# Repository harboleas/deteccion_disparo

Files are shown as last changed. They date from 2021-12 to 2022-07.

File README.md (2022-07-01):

Dispositivo para la detección del disparo de un FAL con un piezoelectrico.
--------------------------------------------------------------------------

En este trabajo se realizaron las siguientes tareas:

* Relevamiento de la señal del piezo, en las condiciones de carga y disparo del FAL, mediante un osciloscopio y su grabacion en formato CSV.

* El desarrollo de un software con interfaz gráfica, en lenguaje C#, 
para simular las señales del piezo en la carga y disparo del FAL.
Este software permite leer los archivos CSV generados por el osciloscopio, y transmitir esa informacion, mediante una comunicación serie, a un Arduino para su procesamiento (en modo simulación).    

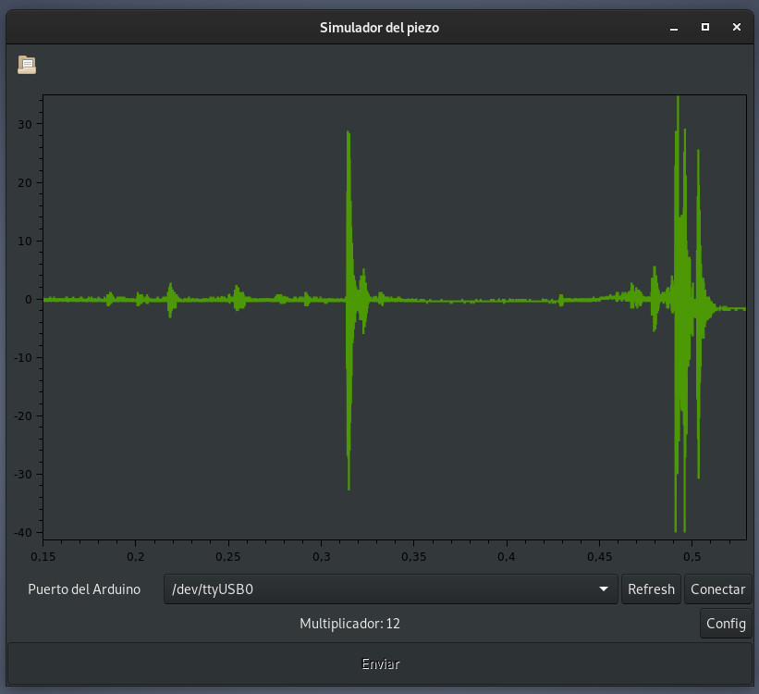
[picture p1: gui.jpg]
GUI


* El desarrollo del firmware para un Arduino que permite analizar la señal que llega del piezo, a través del puerto ADC, y detectar cuando se produce eldisparo del FAL.
El firmware también posee un modo simulación donde obtiene la informacion de la señal por el puerto serie.  

* Diseño en CAD del contenedor del dispositivo y su impresión en 3D
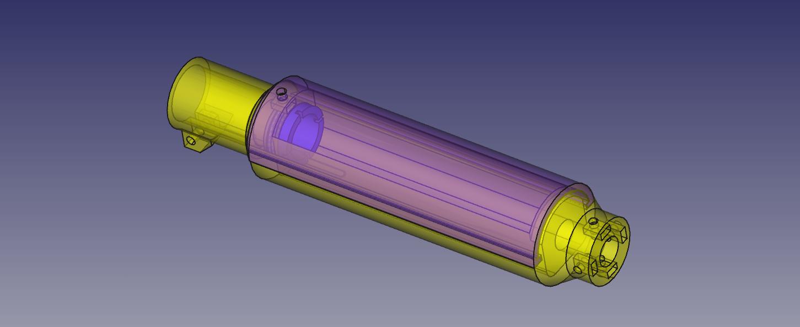
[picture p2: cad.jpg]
Mecanica

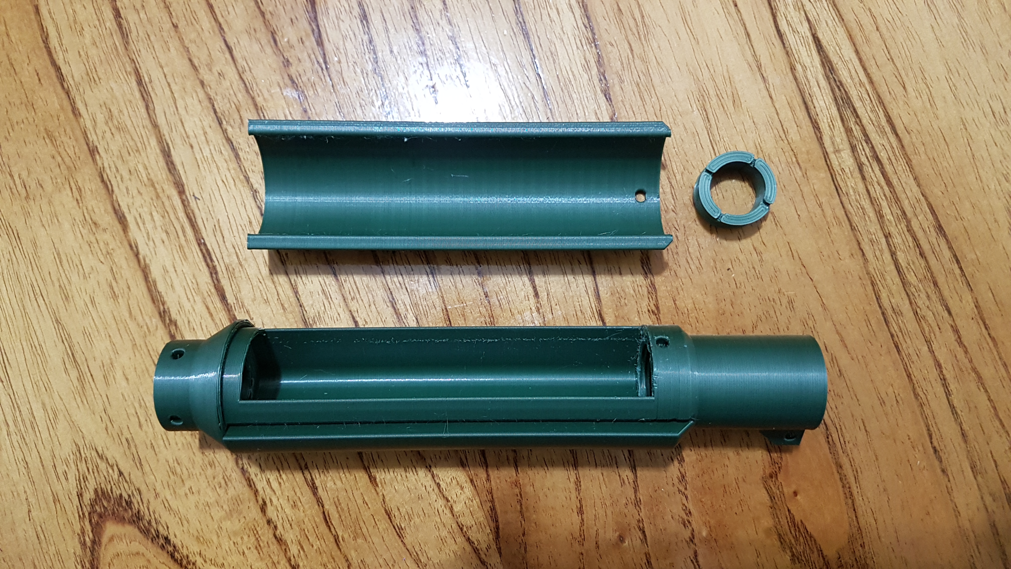
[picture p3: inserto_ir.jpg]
Mecanica2


Maquina de estados para la deteccion de la señal de disparo
-----------------------------------------------------------

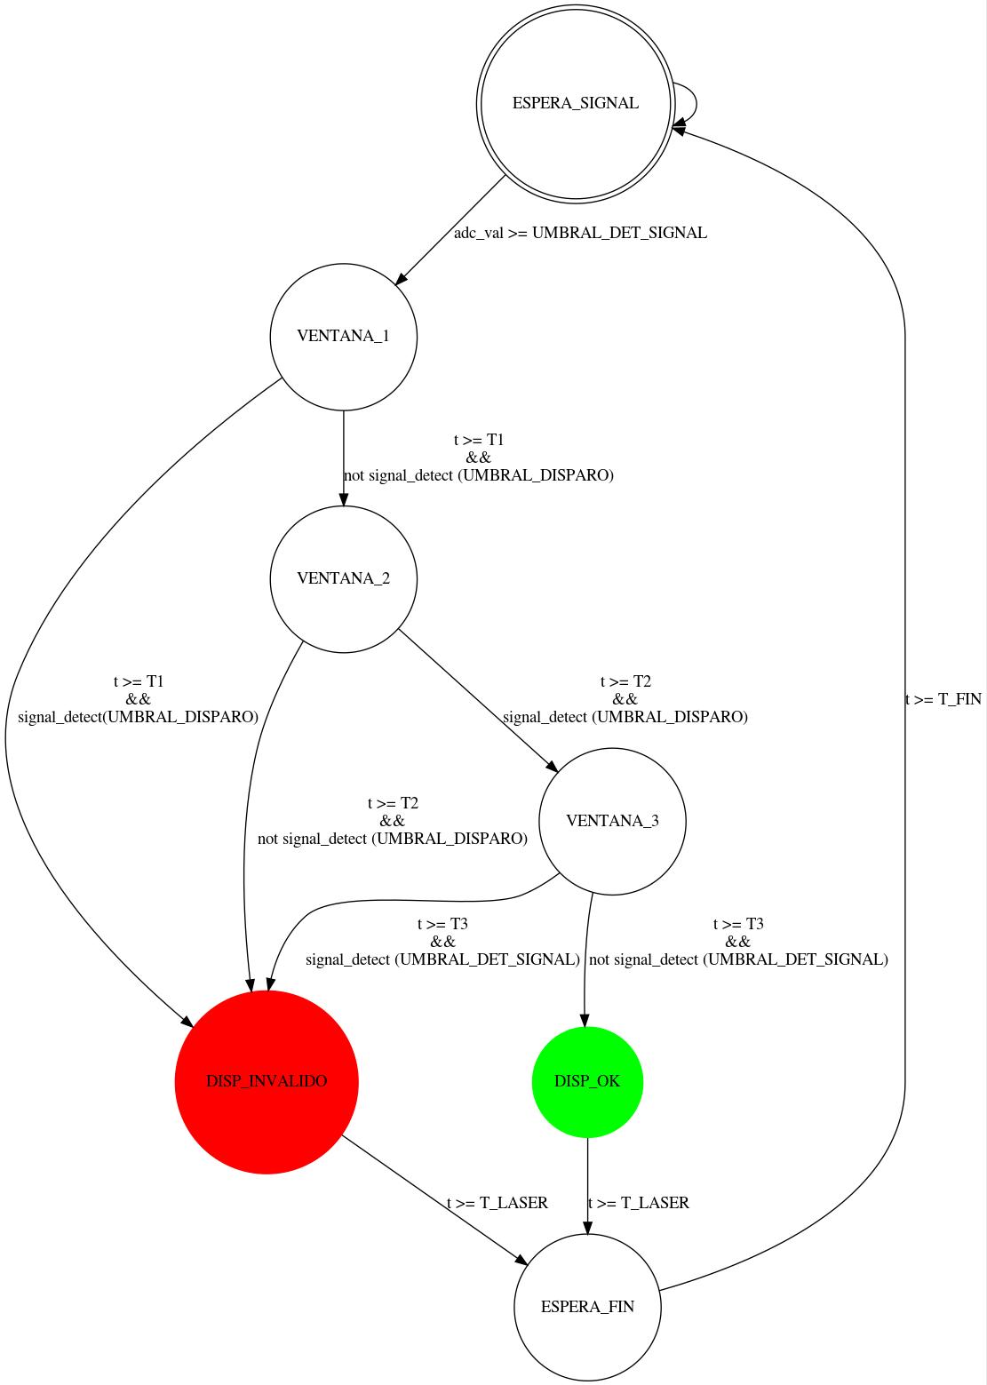
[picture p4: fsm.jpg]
FSM


* Diseño del PCB

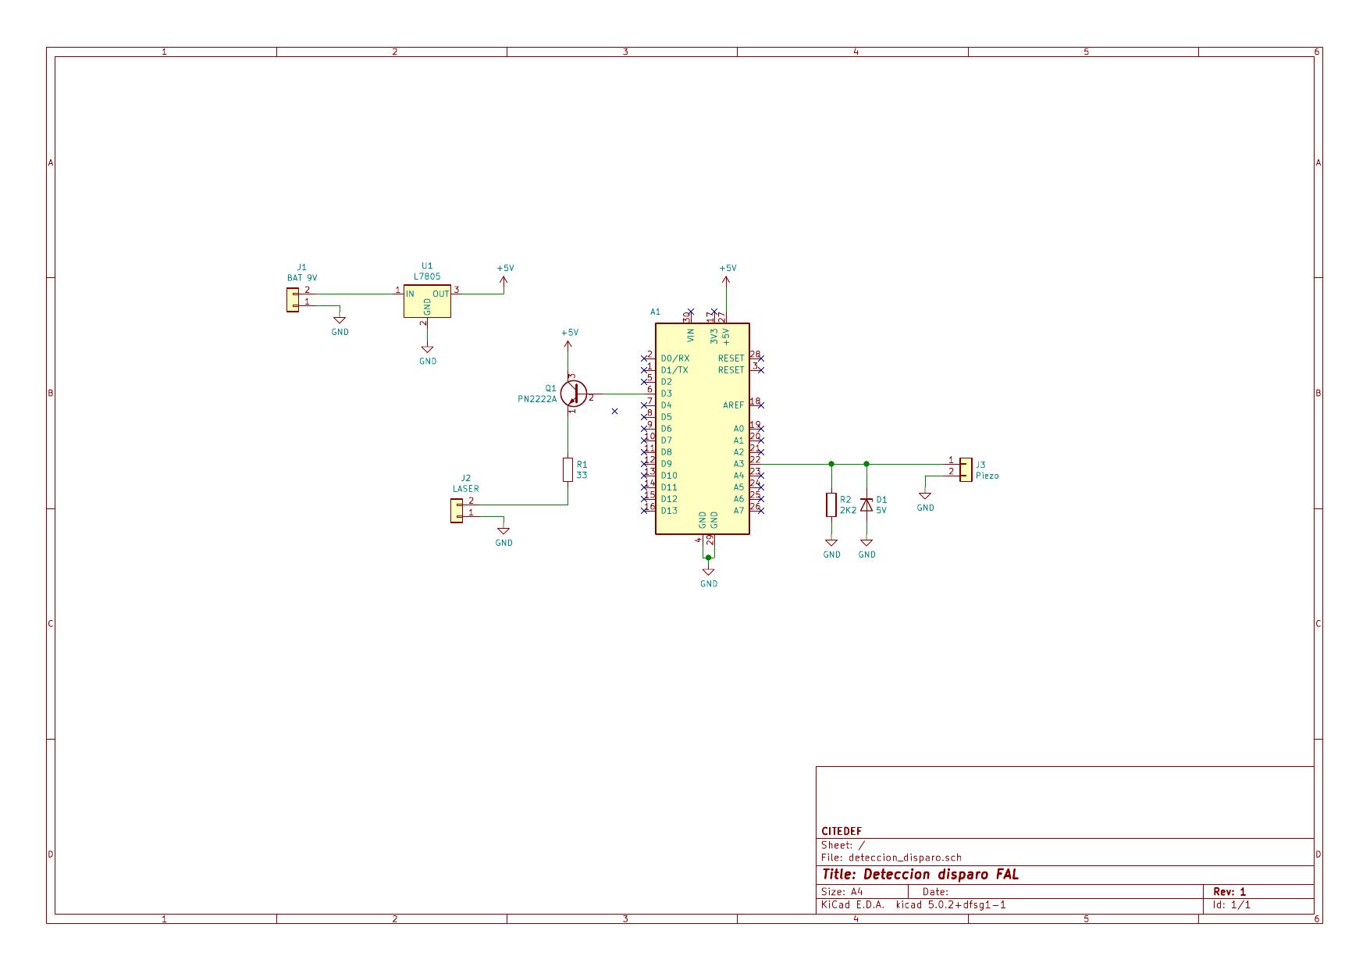
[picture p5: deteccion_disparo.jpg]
PCB


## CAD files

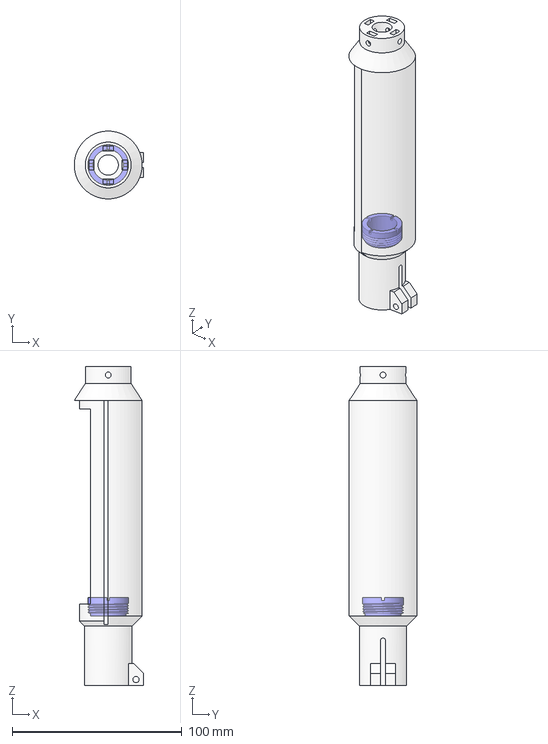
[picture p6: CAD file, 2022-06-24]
mecanica/inserto_ir.FCStd
40.9 x 40.0 x 188.0 mm

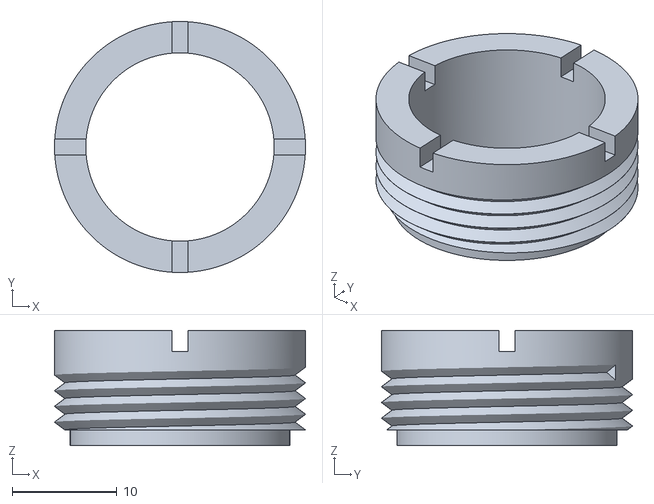
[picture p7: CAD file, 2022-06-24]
mecanica/inserto_ir_rosca.stl
24.0 x 24.0 x 11.0

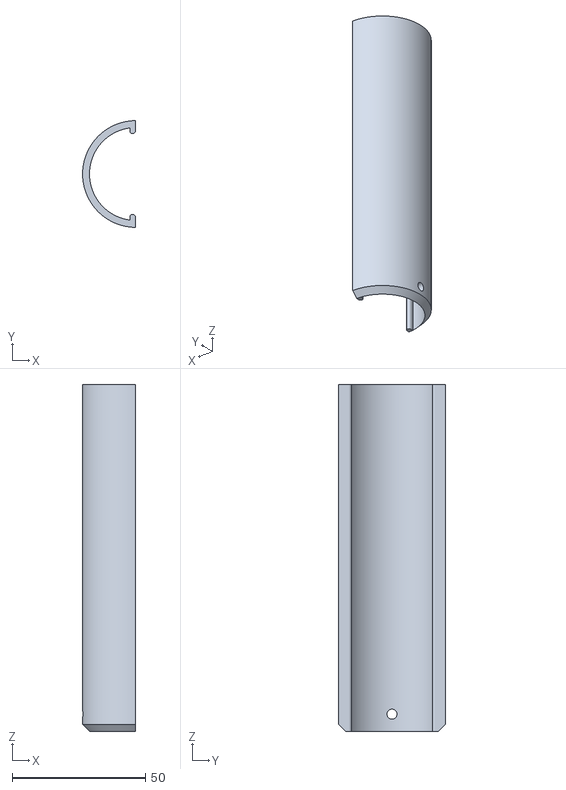
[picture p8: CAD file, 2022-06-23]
mecanica/inserto_ir_tapa.stl
19.8 x 40.0 x 130.0

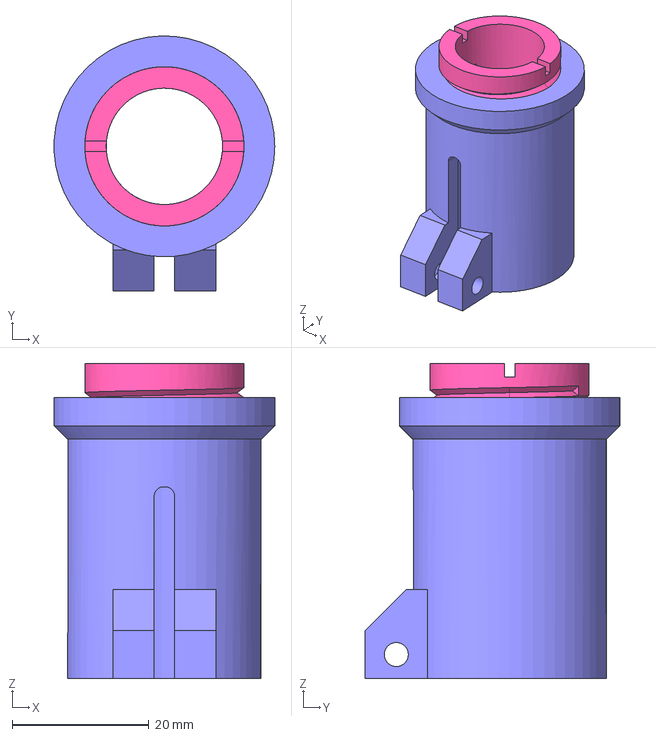
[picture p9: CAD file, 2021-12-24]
mecanica/soporte_piezo.FCStd
32.2 x 37.2 x 46.0 mm

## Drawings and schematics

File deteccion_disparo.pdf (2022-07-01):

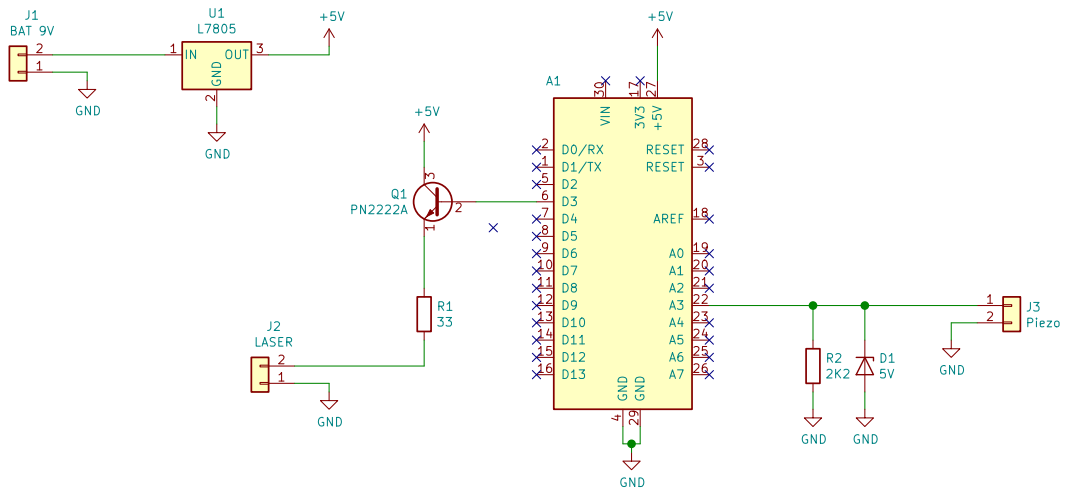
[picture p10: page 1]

File: deteccion_disparo.sch Sheet: / CITEDEF

Id: 1/1 Title: Deteccion disparo FAL

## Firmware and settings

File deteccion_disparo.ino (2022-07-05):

// Deteccion de disparo para SIMTAP

// Descomentar la siguiente linea para simulacion del piezo  
//#define SIMU

// Definicion de pines
#define ADC_PIN 3
#define LASER_PIN 3
#define TESTIGO_PIN 13
#define DISP_INVALIDO_PIN 2

// Umbral para la deteccion
#define UMBRAL_DET_SIGNAL 27 // 0.13V    92   // 0.45 Volts
#define UMBRAL_DISPARO 870// 4.25 Volts

// Duracion de las ventanas de deteccion en microsegundos
#define T1 4000L
#define T2 19000L
#define T3 5000L

// Duracion del pulso del laser en microsegundos
#define T_LASER 1500L

// Tiempo de espera hasta la proxima deteccion
#define T_FIN 150000L

////// Declaracion de variables ////////
enum Estados {
  ESPERA_SIGNAL,
  VENTANA_1,
  VENTANA_2,
  VENTANA_3,
  DISP_INVALIDO,
  DISP_OK,
  ESPERA_FIN};
  
Estados estado;
unsigned long t_0, t;
int adc_val;
bool signal_detect;

// Debido a que en la simulacion no puedo suministrar las muestrar
// con la misma frecuencia que lo realiza el conversor AD
// utilizo un multiplicador para la duracion de las ventanas
int Mult;

////////////////////////////////////////

/////// Simulacion de muestreo ////////

union {
    int val;
    byte bytes[2];
    } dato;

// Obtiene la senal por el USB

int simula_muestreo()
{
    
    if (Serial.available() >= 2)
    {
        Serial.readBytes(dato.bytes, 2);
        return dato.val;
    };

    return 0;

}
////////////////////////////////////////


#define FASTADC 1

// defines for setting and clearing register bits
#ifndef cbi
#define cbi(sfr, bit) (_SFR_BYTE(sfr) &= ~_BV(bit))
#endif
#ifndef sbi
#define sbi(sfr, bit) (_SFR_BYTE(sfr) |= _BV(bit))
#endif

void setup()
{
    
    pinMode(LASER_PIN, OUTPUT);
    pinMode(TESTIGO_PIN, OUTPUT);
    pinMode(DISP_INVALIDO_PIN, OUTPUT);
    Mult = 1;
    estado = ESPERA_SIGNAL;

    #ifdef FASTADC
      // set prescale to 16
      sbi(ADCSRA,ADPS2) ;
      cbi(ADCSRA,ADPS1) ;
      cbi(ADCSRA,ADPS0) ;
    #endif

    #ifdef SIMU
        Serial.begin(115200);  // Solo para simulacion  
        // Lee el valor del multiplicador, el simulador antes de enviar 
        // este dato, resetea el arduino
        Serial.readBytes(dato.bytes, 2);
        Mult = dato.val;
        Serial.println(Mult);
    #endif

}

void loop()
{
    // Tiempo actual
    t = micros();

    // Muestreo 
#ifndef SIMU 
    adc_val = analogRead(ADC_PIN);    
#else
    adc_val = simula_muestreo();   
#endif

// FSM
    switch(estado)
    {
        case ESPERA_SIGNAL:
            if (adc_val >= UMBRAL_DET_SIGNAL)
            {
                estado = VENTANA_1;
                t_0 = t; // Reset del delta t 
                signal_detect = 0;
                #ifdef SIMU 
                    Serial.println(estado); //Para ver el cambio de estado
                #endif 
            }
            break;

        case VENTANA_1:
            if (adc_val >= UMBRAL_DISPARO)    
                signal_detect = true;

            if (t - t_0 >= (T1 * Mult))
            {

                if (signal_detect)
                {
                    estado = DISP_INVALIDO;
                    t_0 = t;
                    signal_detect = false;

                    #ifdef SIMU 
                        Serial.println(estado);
                    #endif 

                }
                else
                {
                    estado = VENTANA_2;
                    t_0 = t;
                    signal_detect = false;

                    #ifdef SIMU 
                        Serial.println(estado);
                    #endif 
                }
                    
            }
            break;

        case VENTANA_2:
            if (adc_val >= UMBRAL_DISPARO)    
                signal_detect = true;

            if (t - t_0 >= (T2 * Mult))
            {

                if (signal_detect)
                {
                    estado = VENTANA_3;
                    t_0 = t;
                    signal_detect = false;

                    #ifdef SIMU 
                        Serial.println(estado);
                    #endif 

                }
                else
                {
                    estado = DISP_INVALIDO;
                    t_0 = t;
                    signal_detect = false;

                    #ifdef SIMU 
                        Serial.println(estado);
                    #endif 
                }
            }
            break;
    
        case VENTANA_3:
            if (adc_val >= UMBRAL_DET_SIGNAL)
                signal_detect = true;

            if (t - t_0 >= (T3 * Mult))
            {
                if (!signal_detect)
                {
                    estado = DISP_OK;
                    t_0 = t;
                    signal_detect = false;
 
                    #ifdef SIMU 
                        Serial.println(estado);
                    #endif 
                }
                else
                {
                    estado = DISP_INVALIDO;
                    t_0 = t;
                    signal_detect = false;

                    #ifdef SIMU 
                        Serial.println(estado);
                    #endif 
                }
            }           
            break;
        
       case DISP_INVALIDO:
            digitalWrite(DISP_INVALIDO_PIN, HIGH);
            if (t - t_0 >= (T_LASER * Mult))
            {
                digitalWrite(DISP_INVALIDO_PIN, LOW);
                estado = ESPERA_FIN;
                t_0 = t;

                #ifdef SIMU 
                    Serial.println(estado);
                #endif 

            }
            break;

        case DISP_OK:
            digitalWrite(LASER_PIN, HIGH);
            digitalWrite(TESTIGO_PIN, HIGH);
            if (t - t_0 >= (T_LASER * Mult))
            {
                digitalWrite(LASER_PIN, LOW);
                digitalWrite(TESTIGO_PIN, LOW);
                estado = ESPERA_FIN;
                t_0 = t;

                #ifdef SIMU 
                    Serial.println(estado);
                #endif 

            }
            break;

        case ESPERA_FIN:
            if (t - t_0 >= (T_FIN * Mult))
            {
                estado = ESPERA_SIGNAL;

                 #ifdef SIMU 
                    Serial.println(estado);
                #endif 

            }
            break;

        default:
            estado = ESPERA_SIGNAL;

   }

}

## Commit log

2021-11-11 working in deteccion y simu_piezo
    [A0012CH1.CSV]
2021-11-17 add visualizacion de cambios de estado en simu
2021-11-17 add mediciones
    [A0012CH1.CSV, no_valido_1.csv, no_valido_2.csv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]
2021-11-19 add boton para setear multiplicador de tiempo
2021-11-19 modif valores de tiempos y umbrales en deteccion_disparo.ino
2021-12-14 modif val. umbrales y simulacion del adc
2021-12-20 modif ADC clock en deteccion_disparo.ino
2021-12-20 modif valores de los umbrales en deteccion_disparo
2021-12-21 add soporte piezo
    [soporte_piezo.FCStd]
2021-12-22 modif. mecanica
    [arandela.stl, soporte_piezo.FCStd, soporte_piezo.stl]
2021-12-22 modif. paso de la rosca del soporte piezo
    [arandela.stl, soporte_piezo.FCStd, soporte_piezo.stl]
2021-12-23 modif. dimensiones soporte_piezo
    [arandela.stl, soporte_piezo.FCStd, soporte_piezo.stl]
2021-12-24 modif mecanica
    [arandela.stl, arandela_disco_chico.stl, arandela_disco_grande.stl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]
2022-05-10 modif. simulador y add mediciones
    [NewFile0.csv, NewFile1.csv, NewFile10.csv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]
2022-06-08 modif gen_raf
    [NewFile0.csv, NewFile1.csv, NewFile10.csv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]
2022-06-08 mov. mediciones
    [NewFile0.csv, NewFile1.csv, NewFile2.csv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]
2022-06-13 modif FSM para deteccion de disparo
2022-06-22 add inserto_ir
    [inserto_ir.FCStd]
2022-06-23 modif inserto_ir
    [inserto_ir.FCStd]
2022-06-23 modif. inserto_ir
    [inserto_ir.FCStd]
2022-06-23 add inserto_ir stls
    [inserto_ir_rosca.stl, inserto_ir_tapa.stl]
2022-06-24 modif rosca inserto_ir
    [inserto_ir.FCStd, inserto_ir_rosca.stl]
2022-06-24 add NOTA para imprimir rosca
2022-06-24 limpieza carpeta mecanica
    [arandela_disco_chico.stl, arandela_disco_grande.stl, soporte_piezo_disco_chico.stl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]
2022-07-01 add circuito
    [deteccion_disparo.kicad_pcb, deteccion_disparo.sch]
2022-07-01 fix error en esquematico
    [deteccion_disparo.sch]
2022-07-01 modif esquematico
    [deteccion_disparo.sch]
2022-07-05 modif umbral deteccion y duracion laser
